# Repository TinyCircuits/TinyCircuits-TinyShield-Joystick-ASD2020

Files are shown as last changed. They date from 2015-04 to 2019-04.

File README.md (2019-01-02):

# TinyCircuits TinyShield Joystick Board
# ASD2020 Rev4

The design files are located under design_files/ for the TinyCircuits ASD2020 Rev 4 PCB.  This is a TinyShield board that has two analog joysticks and two push buttons.

Format is in Cadsoft Eagle format - Eagle version 6.2 was used for the original design.

For more infomation on this, check out the product page at TinyCircuits.com:  https://tinycircuits.com/collections/sensors/products/joystick-tinyshield

#License:

Design by TinyCircuits.
All design files are released under the Creative Commons Attribution Share-Alike 3.0 License, see the following link for details: http://creativecommons.org/licenses/by-sa/3.0

All text above must be included in any redistribution or derived design

This project uses designs and concepts developed as part of the Arduino project and the LilyPad project.  The TinyCircuits design files themselves (schematics, PCB and libraries) are not directly derived from these works' design files and have been created new, however the concepts and basic architecture behind the TinyDuino and TinyLily products are derived and we thank the hard work of the organizations below for their contributions to open-source hardware:
  
Original Arduino Uno Design by Team Arduino

LilyPad Arduino Design by Leah Buechley and Sparkfun Electronics

Please support the open-source hardware community

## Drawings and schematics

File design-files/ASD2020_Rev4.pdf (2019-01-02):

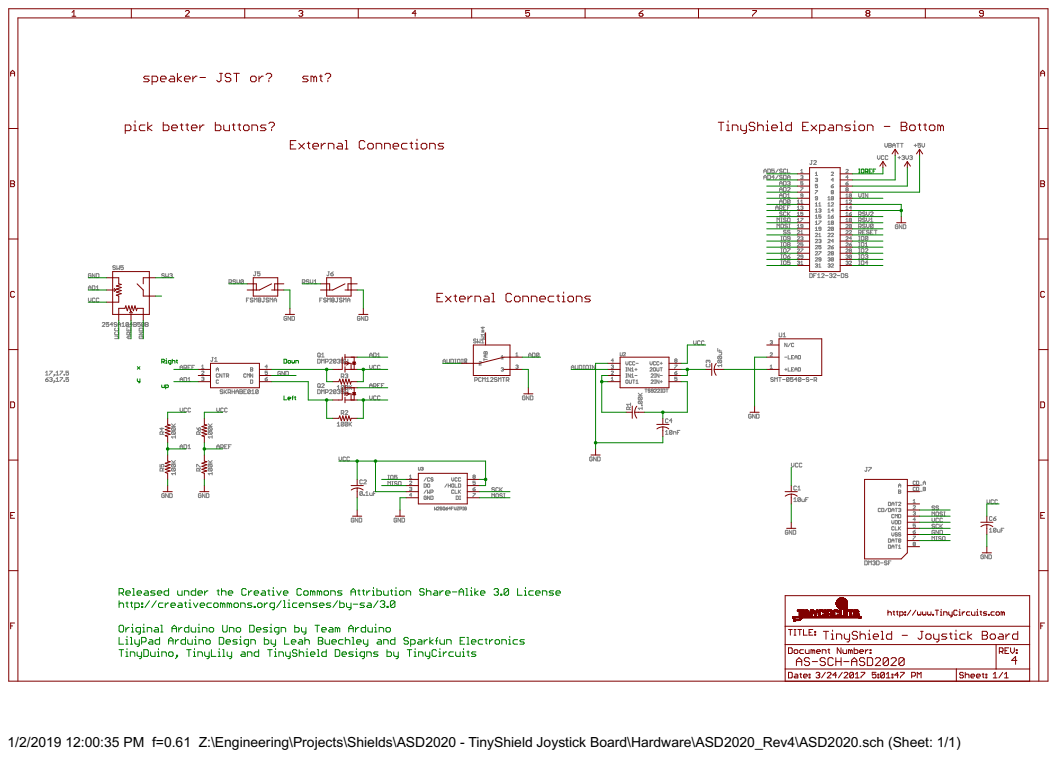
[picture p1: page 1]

1/2/2019 12:00:35 PM f=0.61 Z:\Engineering\Projects\Shields\ASD2020 - TinyShield Joystick Board\Hardware\ASD2020_Rev4\ASD2020.sch (Sheet: 1/1)

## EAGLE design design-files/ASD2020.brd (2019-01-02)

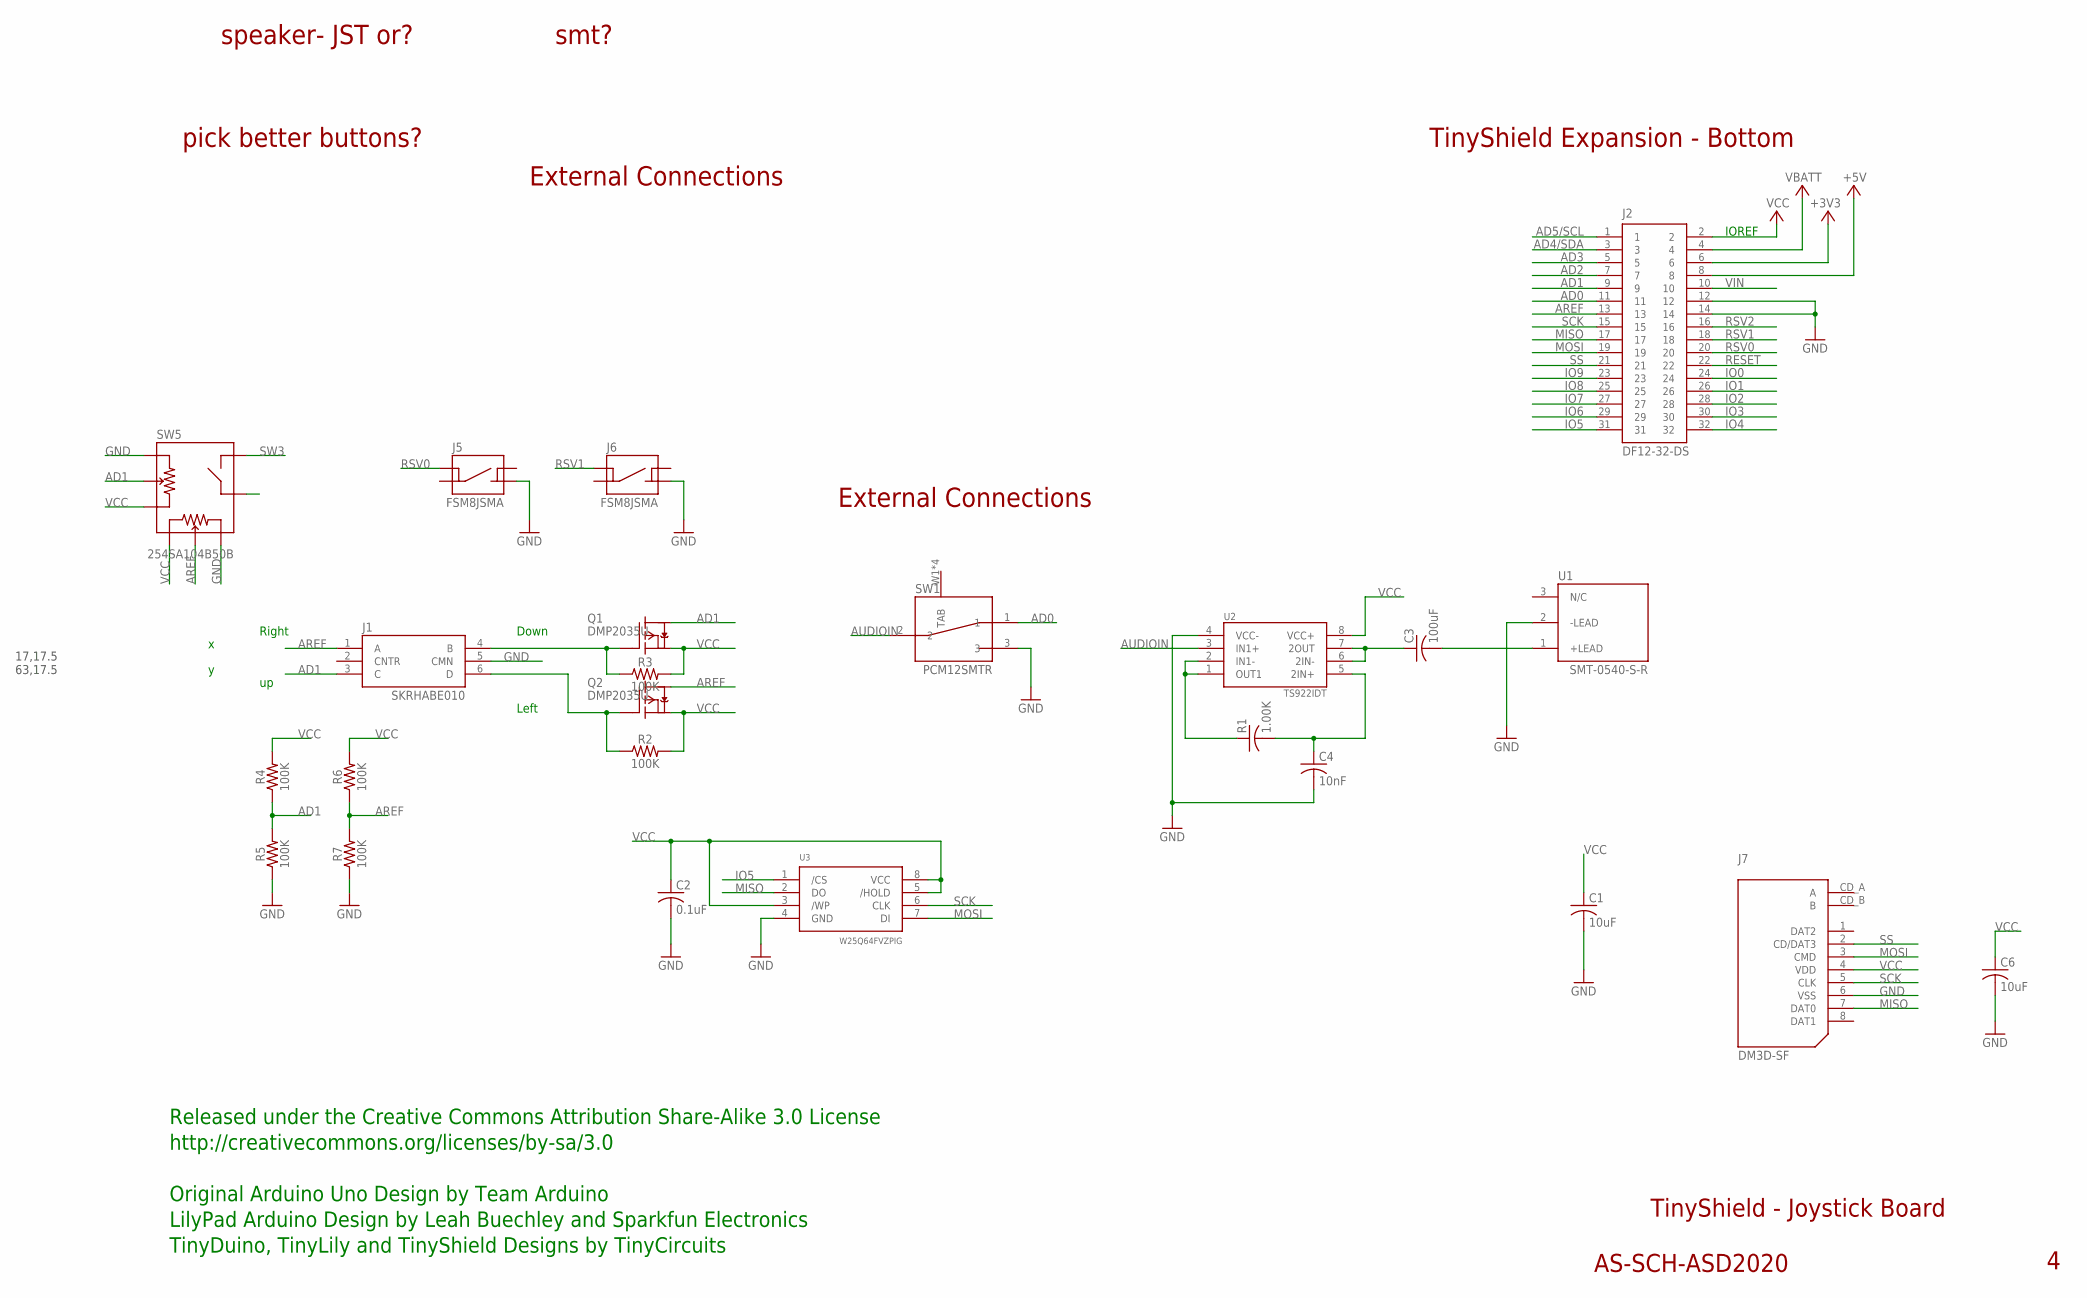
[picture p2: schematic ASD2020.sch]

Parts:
C1: 10uF; C0603; PARTNO AS-ITM-00002
C2: 0.1uF; C0402
C3: 100uF; C1206
C4: 10nF; C0402
C6: 10uF; C0603
J1: SKRHABE010; SKRHA
J2: DF12-32-DS; PARTNO AS-ITM-00012
J5, J6: FSM8JSMA; SWITCH-FSM/JSM
J7: DM3D-SF; SD_CARD
Q1, Q2: DMP2035U; SOT23
R1: 1.00K; C0402; PARTNO AS-ITM-00008
R2: 100K; 0402
R3, R4, R5, R6, R7: 100K; 0402; PARTNO AS-ITM-00004
SW1: PCM12SMTR
SW5: 254SA104B50B; JOYSTICK_CTS_254
U1: SMT-0540-S-R
U2: TS922IDT; SO-08-COMPACT
U3: W25Q64FVZPIG; 8-WSON-6X5

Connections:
+3V3: J2.6
+5V: J2.8
AD0: J2.11, SW1.1
AD1: J1.3 (C), J2.9, Q1.C (D), R4.1, R5.2, SW5.A2
AD2: J2.7
AD3: J2.5
AD4/SDA: J2.3
AD5/SCL: J2.1
AREF: J1.1 (A), J2.13, Q2.C (D), R6.1, R7.2, SW5.B2
AUDIOIN: SW1.2, U2.3 (IN1+)
GND: C1.2, C2.2, C4.2, C6.2, J1.5 (CMN), J2.12, J2.14, J5.P$3 (2), J6.P$3 (2), J7.6 (VSS), R5.1, R7.1, SW1.3, SW5.A1, SW5.B3, U1.2 (-LEAD), U2.4 (VCC-), U3.4 (GND)
IO0: J2.24
IO1: J2.26
IO2: J2.28
IO3: J2.30
IO4: J2.32
IO5: J2.31, U3.1 (/CS)
IO6: J2.29
IO7: J2.27
IO8: J2.25
IO9: J2.23
MISO: J2.17, J7.7 (DAT0), U3.2 (DO)
MOSI: J2.19, J7.3 (CMD), U3.7 (DI)
unnamed: C3.1, U2.6 (2IN-), U2.7 (2OUT)
unnamed: C3.2, U1.1 (+LEAD)
unnamed: C4.1, R1.2, U2.5 (2IN+)
unnamed: R1.1, U2.1 (OUT1), U2.2 (IN1-)
unnamed: J1.4 (B), Q1.B (G), R3.1
unnamed: J1.6 (D), Q2.B (G), R2.1
RESET: J2.22
RSV0: J2.20, J5.P$1 (3)
RSV1: J2.18, J6.P$1 (3)
RSV2: J2.16
SCK: J2.15, J7.5 (CLK), U3.6 (CLK)
SS: J2.21, J7.2 (CD/DAT3)
SW3: SW5.S1
VBATT: J2.4
VCC: C1.1, C2.1, C6.1, J2.2, J7.4 (VDD), Q1.E (S), Q2.E (S), R2.2, R3.2, R4.2, R6.2, SW5.A3, SW5.B1, U2.8 (VCC+), U3.3 (/WP), U3.5 (/HOLD), U3.8 (VCC)
VIN: J2.10

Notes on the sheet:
TinyShield Expansion - Bottom
TinyShield - Joystick Board
AS-SCH-ASD2020
IOREF
Released under the Creative Commons Attribution Share-Alike 3.0 License
http://creativecommons.org/licenses/by-sa/3.0
LilyPad Arduino Design by Leah Buechley and Sparkfun Electronics
TinyDuino, TinyLily and TinyShield Designs by TinyCircuits
Original Arduino Uno Design by Team Arduino
External Connections
17,17.5 63,17.5
speaker- JST or?
pick better buttons?
smt?
Right
Left
Down

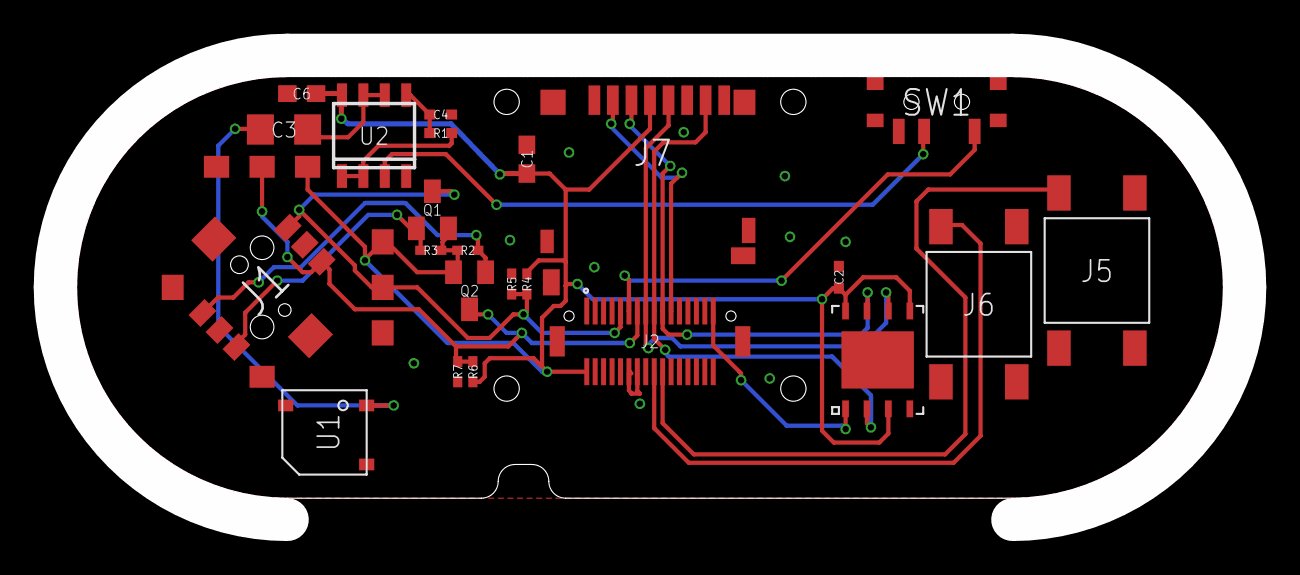
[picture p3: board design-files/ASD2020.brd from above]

Board: 2 copper layers, 68.0 x 25.0 mm, 25 parts (0 on the bottom side), 19 nets.

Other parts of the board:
U$1: DOCFIELD-TINYCIRCUITS-PCB

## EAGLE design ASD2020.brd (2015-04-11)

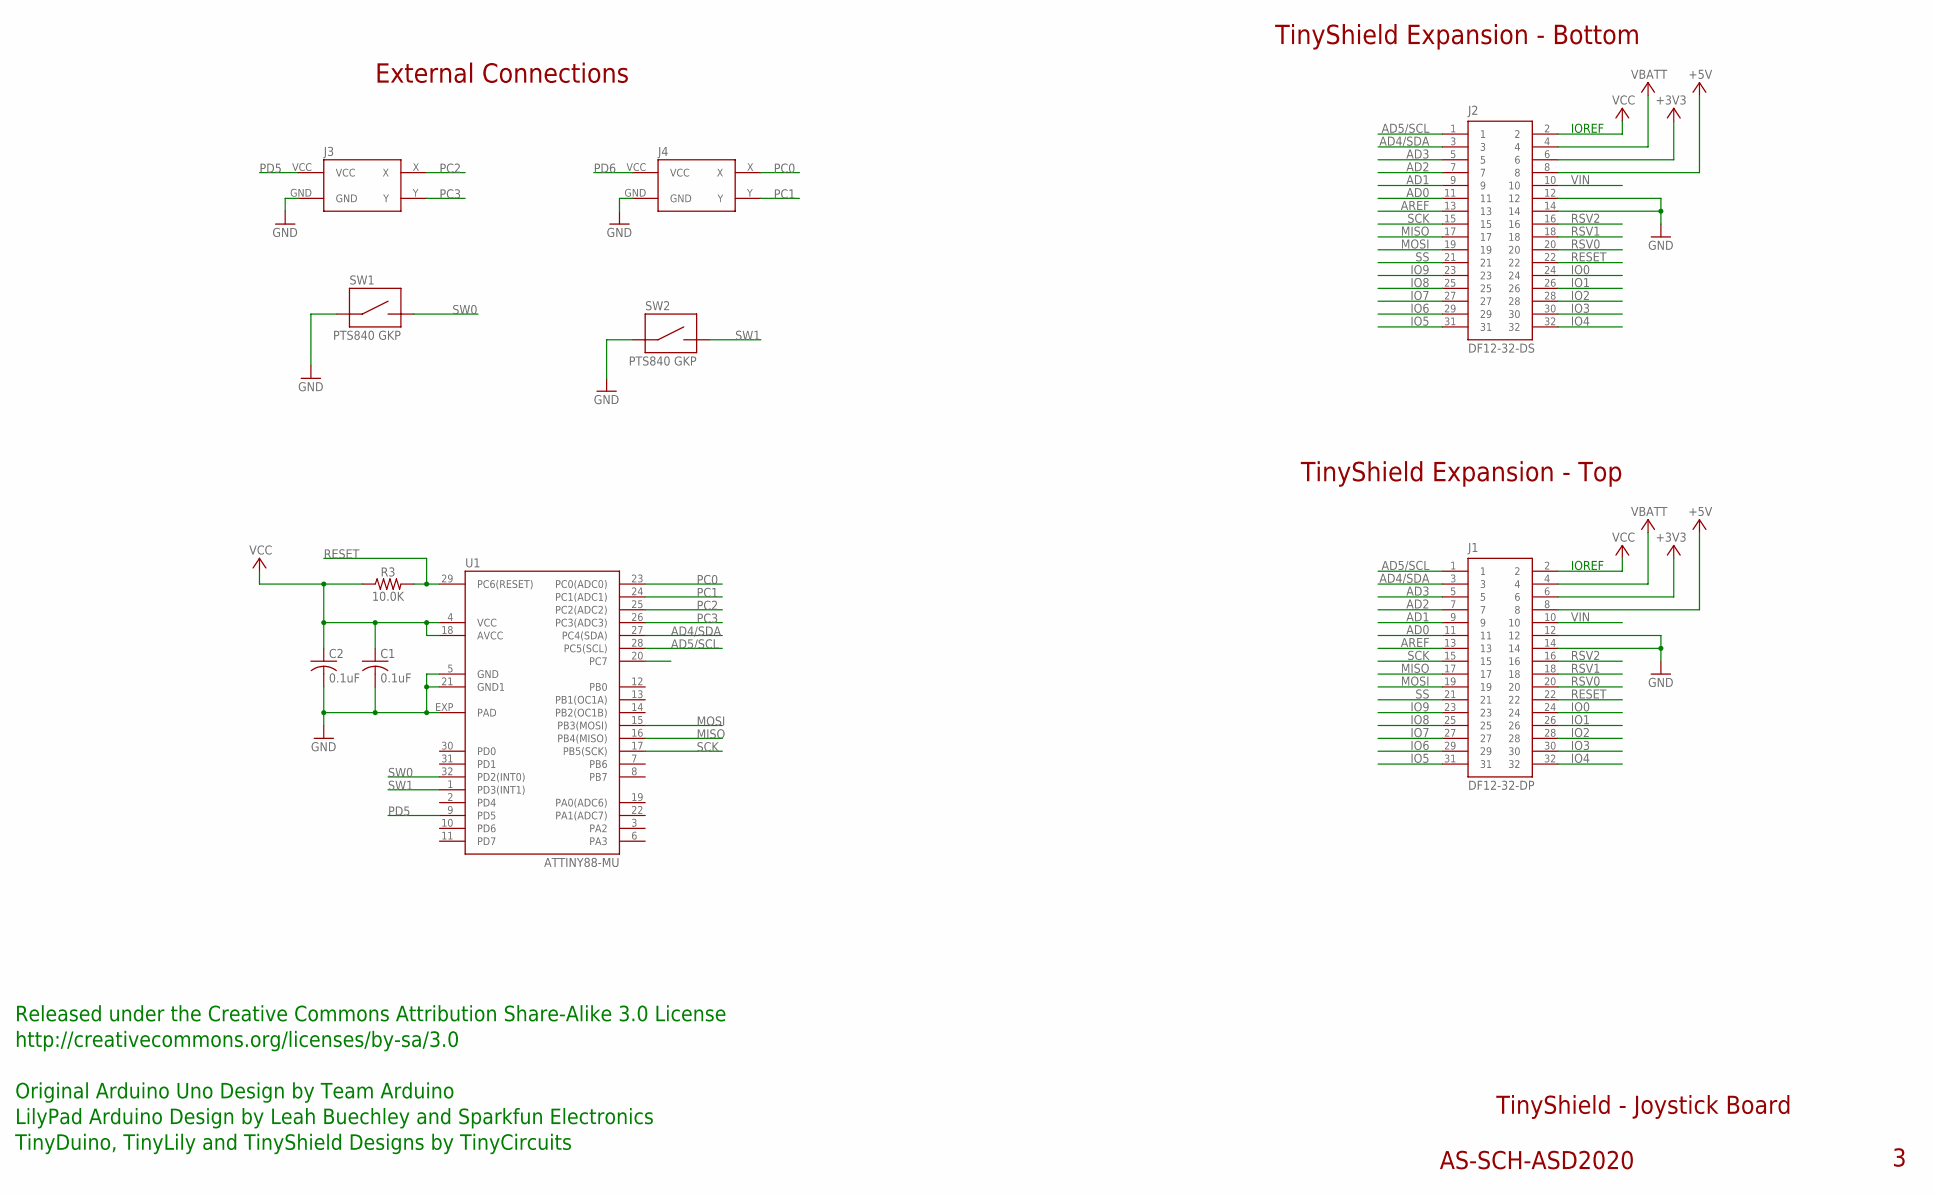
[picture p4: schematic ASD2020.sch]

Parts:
C1, C2: 0.1uF; C0402
J1: DF12-32-DP; PARTNO AS-ITM-00015
J2: DF12-32-DS; PARTNO AS-ITM-00012
J3, J4: AS-ITM-00235; PSPJOYSTICK
R3: 10.0K; 0402
SW1, SW2: PTS840 GKP; PTS840GKP
U1: ATTINY88-MU; ATMEL_QFN32

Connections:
+3V3: J1.6, J2.6
+5V: J1.8, J2.8
AD0: J1.11, J2.11
AD1: J1.9, J2.9
AD2: J1.7, J2.7
AD3: J1.5, J2.5
AD4/SDA: J1.3, J2.3, U1.27 (PC4(SDA))
AD5/SCL: J1.1, J2.1, U1.28 (PC5(SCL))
AREF: J1.13, J2.13
GND: C1.2, C2.2, J1.12, J1.14, J2.12, J2.14, J3.GND, J4.GND, SW1.1, SW1.2 (1), SW2.1, SW2.2 (1), U1.5 (GND), U1.21 (GND1), U1.EXP (PAD)
IO0: J1.24, J2.24
IO1: J1.26, J2.26
IO2: J1.28, J2.28
IO3: J1.30, J2.30
IO4: J1.32, J2.32
IO5: J1.31, J2.31
IO6: J1.29, J2.29
IO7: J1.27, J2.27
IO8: J1.25, J2.25
IO9: J1.23, J2.23
MISO: J1.17, J2.17, U1.16 (PB4(MISO))
MOSI: J1.19, J2.19, U1.15 (PB3(MOSI))
PC0: J4.X, U1.23 (PC0(ADC0))
PC1: J4.Y, U1.24 (PC1(ADC1))
PC2: J3.X, U1.25 (PC2(ADC2))
PC3: J3.Y, U1.26 (PC3(ADC3))
PD5: J3.VCC, U1.9 (PD5)
PD6: J4.VCC, U1.20 (PC7)
RESET: J1.22, J2.22, R3.2, U1.29 (PC6(RESET))
RSV0: J1.20, J2.20
RSV1: J1.18, J2.18
RSV2: J1.16, J2.16
SCK: J1.15, J2.15, U1.17 (PB5(SCK))
SS: J1.21, J2.21
SW0: SW1.3 (2), SW1.4 (2), U1.32 (PD2(INT0))
SW1: SW2.3 (2), SW2.4 (2), U1.1 (PD3(INT1))
VBATT: J1.4, J2.4
VCC: C1.1, C2.1, J1.2, J2.2, R3.1, U1.4 (VCC), U1.18 (AVCC)
VIN: J1.10, J2.10

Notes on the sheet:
TinyShield Expansion - Bottom
TinyShield - Joystick Board
AS-SCH-ASD2020
TinyShield Expansion - Top
IOREF
Released under the Creative Commons Attribution Share-Alike 3.0 License
http://creativecommons.org/licenses/by-sa/3.0
LilyPad Arduino Design by Leah Buechley and Sparkfun Electronics
TinyDuino, TinyLily and TinyShield Designs by TinyCircuits
Original Arduino Uno Design by Team Arduino
External Connections

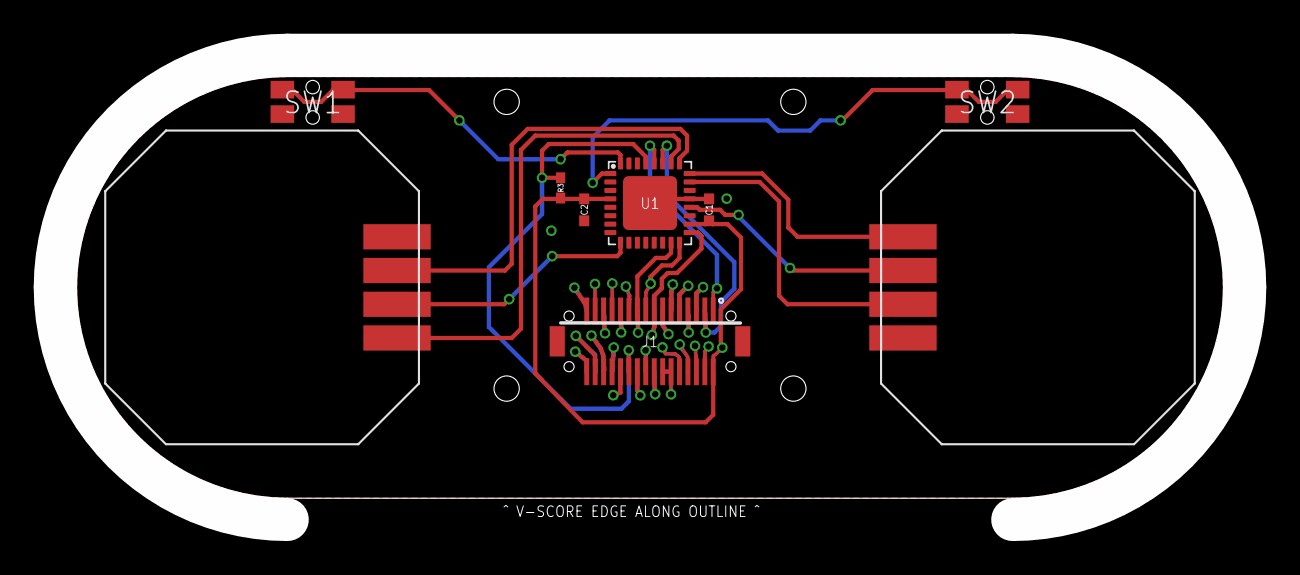
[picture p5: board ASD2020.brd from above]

Board: 2 copper layers, 68.0 x 25.0 mm, 11 parts (1 on the bottom side), 39 nets.

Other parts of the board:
U$1: DOCFIELD-TINYCIRCUITS-PCB

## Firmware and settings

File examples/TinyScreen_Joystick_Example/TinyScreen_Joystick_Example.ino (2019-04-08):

/************************************************************************
 * This tutorial shows how the TinyShield Joystick board's values can be
 * read using a TinyScreen+ processor board. The TinyScreen+ also displays
 * graphics that prove the joystick outputs are being read properly.
 *
 * Hardware by: TinyCircuits
 * Written by: Tony Batey for TinyCircuits
 *
 * Initiated: Mon. 11/20/2015 
 * Updated: Tue. 04/08/2019
 ************************************************************************/

// Libraries
#include <TinyScreen.h>
#include <SPI.h>
#include <Wire.h>

// TinyScreen+ variables
TinyScreen display = TinyScreen(TinyScreenPlus);
int background = TS_8b_Black;

// Color constants
#define	BLACK           0x00
#define	BLUE            0xE0
#define	RED             0x03
#define	GREEN           0x1C
#define WHITE           0xFF
#define	GREY            0x6D

// Global variables to hold joystick data
int RX=0;
int RY=0;
int LX=0;
int LY=0;
byte leftButton=0;
byte rightButton=0;

#if defined(ARDUINO_ARCH_SAMD)
 #define SerialMonitorInterface SerialUSB
#else
 #define SerialMonitorInterface Serial
#endif

// Begin Serial, 
void setup(void) {
  Wire.begin();
  SerialMonitorInterface.begin(9600);
  display.begin();
}

void loop() {
  getJoystick();
  
  byte color;
  byte activeColor;
  
  if(leftButton)activeColor=RED;else activeColor=GREEN;
  if(LY>200)color=activeColor;else color=GREY;
  drawUpArrow(24,8,10,color);
  if(LY<-200)color=activeColor;else color=GREY;
  drawDownArrow(24,56,10,color);
  if(LX>200)color=activeColor;else color=GREY;
  drawRightArrow(47,32,10,color);
  if(LX<-200)color=activeColor;else color=GREY;
  drawLeftArrow(1,32,10,color);
  if(abs(LY)<200 && abs(LX)<200)color=activeColor;else color=GREY;
  drawFilledCircle(24, 32, 8, color);
  
  if(rightButton)activeColor=RED;else activeColor=GREEN;
  if(RY>200)color=activeColor;else color=GREY;
  drawUpArrow(24+48,8,10,color);
  if(RY<-200)color=activeColor;else color=GREY;
  drawDownArrow(24+48,56,10,color);
  if(RX>200)color=activeColor;else color=GREY;
  drawRightArrow(47+48,32,10,color);
  if(RX<-200)color=activeColor;else color=GREY;
  drawLeftArrow(1+48,32,10,color);
  if(abs(RY)<200 && abs(RX)<200)color=activeColor;else color=GREY;
  drawFilledCircle(24+48, 32, 8, color);
  
  delay(50);
  
}


/****************************** Various Drawing Functions ***********************************/

void drawFilledCircle(int x0, int y0, int radius, uint8_t color)
{
  int x = radius;
  int y = 0;
  int radiusError = 1-x;
 
  while(x >= y)
  {
    display.drawLine(x0+x,y0+y,x0-x,y0+y,color);
    display.drawLine(x0+y,y0+x,x0-y,y0+x,color);
    display.drawLine(x0-x,y0-y,x0+x,y0-y,color);
    display.drawLine(x0-y,y0-x,x0+y,y0-x,color);
    y++;
    if (radiusError<0)
    {
      radiusError += 2 * y + 1;
    }
    else
    {
      x--;
      radiusError += 2 * (y - x) + 1;
    }
  }
}

void drawDownArrow(int x, int y, int height, byte color){
  for(int i=0;i<=height;i++){
    display.drawLine(x-i,y-i,x+i,y-i,color);
    delayMicroseconds(100);
  }
}

void drawUpArrow(int x, int y, int height, byte color){
  for(int i=0;i<=height;i++){
    display.drawLine(x-i,y+i,x+i,y+i,color);
    delayMicroseconds(100);
  }
}

void drawRightArrow(int x, int y, int height, byte color){
  for(int i=0;i<=height;i++){
    display.drawLine(x-i,y+i,x-i,y-i,color);
    delayMicroseconds(100);
  }
}

void drawLeftArrow(int x, int y, int height, byte color){
  for(int i=0;i<=height;i++){
    display.drawLine(x+i,y+i,x+i,y-i,color);
    delayMicroseconds(100);
  }
}


// Reading joystick values, storing in global variables
void getJoystick(){
  Wire.requestFrom(0x22,6);
  int data[4];
  for(int i=0;i<4;i++){
    data[i]=Wire.read();
  }
  byte lsb=Wire.read();
  byte buttons=~Wire.read();
  leftButton=buttons&4;
  rightButton=buttons&8;
  for(int i=0;i<4;i++){
    data[i]<<=2;
    data[i]|= ((lsb>>(i*2))&3);
    data[i]-=511;
  }
  RX=data[0];
  RY=-data[1];
  LX=-data[2];
  LY=data[3];
}
